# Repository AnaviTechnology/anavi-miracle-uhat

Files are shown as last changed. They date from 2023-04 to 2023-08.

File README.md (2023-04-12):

# ANAVI Miracle uHAT

ANAVI Miracle uHAT is an open source hardware Raspberry Pi add-on board for controlling NeoPixel RGB LED strip powered by free and open source software. It features:

* Slot for addressable NeoPixel RGB LED strip like WS2812B, WS2812B, WS2811, etc.
* Power input barrel jack for the addressable RGB LED strip
* Slot for PIR motion sensor
* Slot for I2C mini OLED display
* Slots for up to 3 plug and play I2C sensors for temperature, barometric pressure, humidity and light
* UART (Universal asynchronous receiver/transmitter) pins for debugging
* EEPROM

# License

The project is released under the [Creative Commons Attribution-ShareAlike 4.0 International (CC BY-SA 4.0)](https://creativecommons.org/licenses/by-sa/4.0/).

Note: This is a human-readable summary of (and not a substitute for) the [license](https://creativecommons.org/licenses/by-sa/4.0/legalcode).

You are free to:

Share — copy and redistribute the material in any medium or format Adapt — remix, transform, and build upon the material for any purpose, even commercially. The licensor cannot revoke these freedoms as long as you follow the license terms. Under the following terms:

Attribution — You must give appropriate credit, provide a link to the license, and indicate if changes were made. You may do so in any reasonable manner, but not in any way that suggests the licensor endorses you or your use. ShareAlike — If you remix, transform, or build upon the material, you must distribute your contributions under the same license as the original. No additional restrictions — You may not apply legal terms or technological measures that legally restrict others from doing anything the license permits. Notices:

You do not have to comply with the license for elements of the material in the public domain or where your use is permitted by an applicable exception or limitation. No warranties are given. The license may not give you all of the permissions necessary for your intended use. For example, other rights such as publicity, privacy, or moral rights may limit how you use the material.

You will have to provide a link to the original creator of the project https://www.anavi.technology on any documentation or website.

Credit can be attributed through a link to the creator website: https://www.anavi.technology

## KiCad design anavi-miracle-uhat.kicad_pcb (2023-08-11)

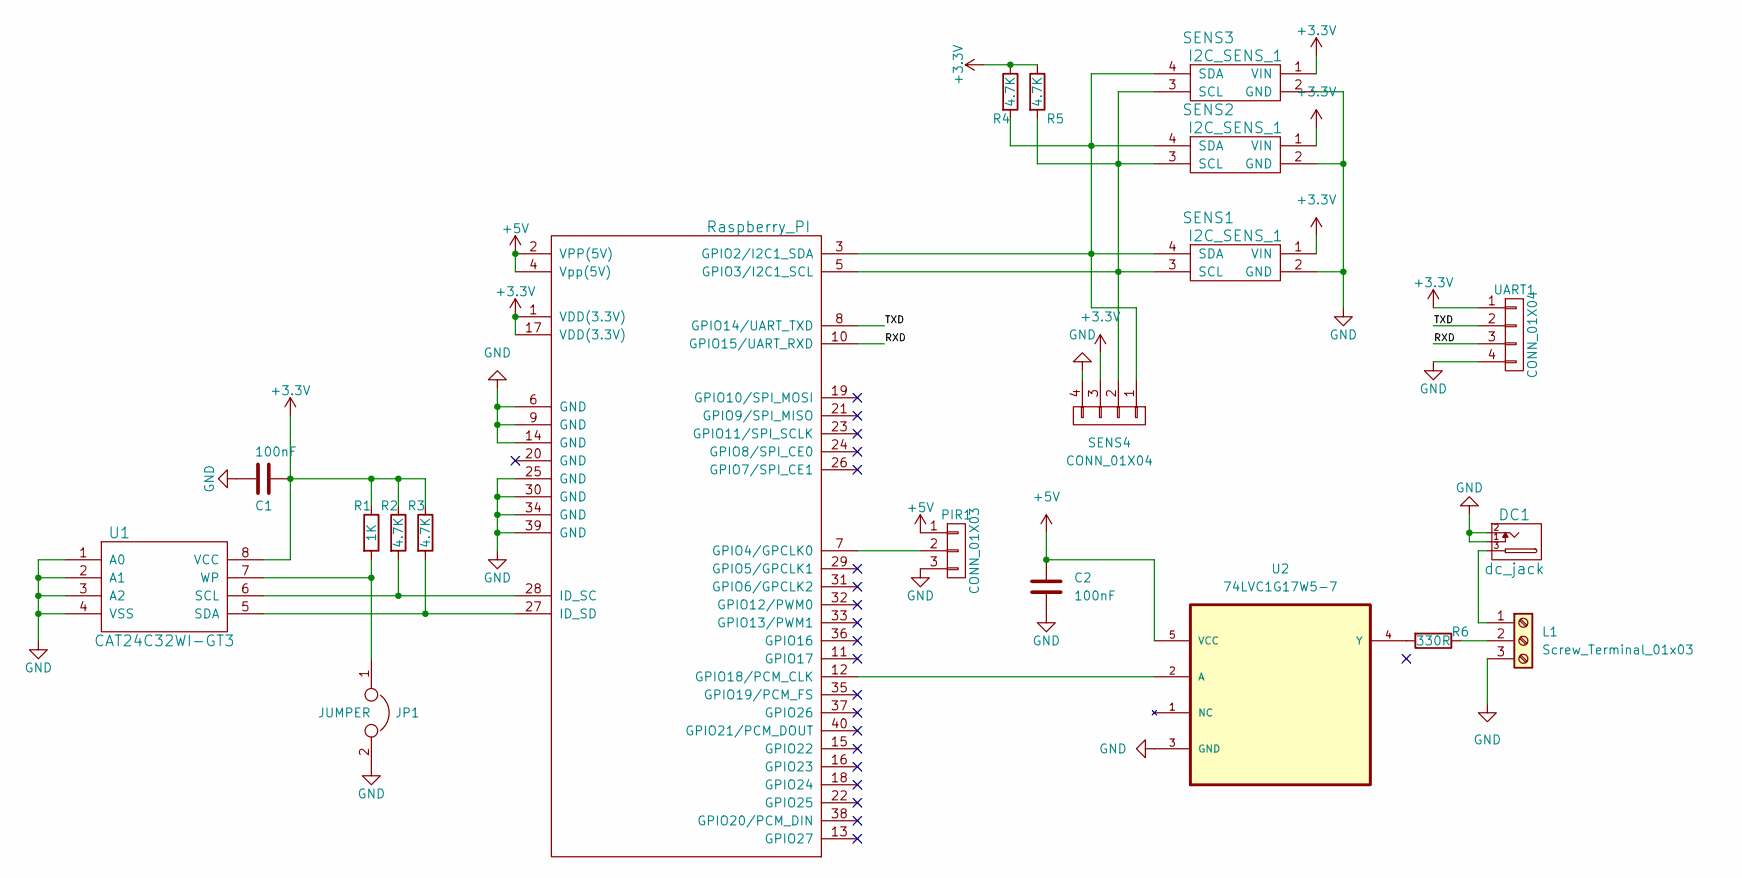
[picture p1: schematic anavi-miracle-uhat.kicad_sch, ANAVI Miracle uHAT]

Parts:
C1, C2: 100nF; C_0603_1608Metric_Pad1.08x0.95mm_HandSolder
DC1: dc_jack; dc_socket
JP1: JUMPER; PinHeader_1x02_P2.54mm_Vertical
L1: Screw_Terminal_01x03; TerminalBlock_Phoenix_MKDS-1,5-3_1x03_P5.00mm_Horizontal
PIR1: CONN_01X03; PinHeader_1x03_P2.54mm_Vertical
R1: 1K; R_0603_HandSoldering
R2, R3, R4, R5: 4.7K; R_0603_HandSoldering
R6: 330R; R_0603_1608Metric_Pad0.98x0.95mm_HandSolder
RASP_CONN1: Raspberry_PI; PinHeader_2x20_P2.54mm_Vertical
SENS1, SENS2, SENS3: I2C_SENS_1; PinHeader_1x04_P2.54mm_Vertical
SENS4: CONN_01X04; PinHeader_1x04_P2.54mm_Vertical
U1: CAT24C32WI-GT3; DIP-8_W7.62mm
U2: 74LVC1G17W5-7; SOT95P280X145-5N; MPN 74LVC1G17W5-7
UART1: CONN_01X04; PinHeader_1x04_P2.54mm_Vertical

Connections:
+3V3: C1.1, R1.1, R2.1, R3.1, R4.1, R5.1, RASP_CONN1.1 (VDD(3.3V)), RASP_CONN1.17 (VDD(3.3V)), SENS1.1 (VIN), SENS2.1 (VIN), SENS3.1 (VIN), SENS4.3, U1.8 (VCC), UART1.1; also elsewhere on the board
+5V: C2.1, PIR1.1, RASP_CONN1.2 (VPP(5V)), RASP_CONN1.4 (Vpp(5V)), U2.5 (VCC); also elsewhere on the board
/RXD: RASP_CONN1.10 (GPIO15/UART_RXD), UART1.3; also elsewhere on the board
/TXD: RASP_CONN1.8 (GPIO14/UART_TXD), UART1.2; also elsewhere on the board
GND: C1.2, C2.2, DC1.1, DC1.2, JP1.2, L1.3, PIR1.3, RASP_CONN1.6 (GND), RASP_CONN1.9 (GND), RASP_CONN1.14 (GND), RASP_CONN1.25 (GND), RASP_CONN1.30 (GND), RASP_CONN1.34 (GND), RASP_CONN1.39 (GND), SENS1.2 (GND), SENS2.2 (GND), SENS3.2 (GND), SENS4.4, U1.1 (A0), U1.2 (A1), U1.3 (A2), U1.4 (VSS), U2.3 (GND), UART1.4; also elsewhere on the board
unnamed: DC1.3, L1.1
unnamed: JP1.1, R1.2, U1.7 (WP)
unnamed: L1.2, R6.1
unnamed 8: PIR1.2, RASP_CONN1.7 (GPIO4/GPCLK0); also elsewhere on the board
unnamed: R2.2, RASP_CONN1.28 (ID_SC), U1.6 (SCL)
unnamed: R3.2, RASP_CONN1.27 (ID_SD), U1.5 (SDA)
unnamed: R4.2, RASP_CONN1.3 (GPIO2/I2C1_SDA), SENS1.4 (SDA), SENS2.4 (SDA), SENS3.4 (SDA), SENS4.1
unnamed: R5.2, RASP_CONN1.5 (GPIO3/I2C1_SCL), SENS1.3 (SCL), SENS2.3 (SCL), SENS3.3 (SCL), SENS4.2
unnamed: R6.2, U2.4 (Y)
unnamed: RASP_CONN1.12 (GPIO18/PCM_CLK), U2.2 (A)

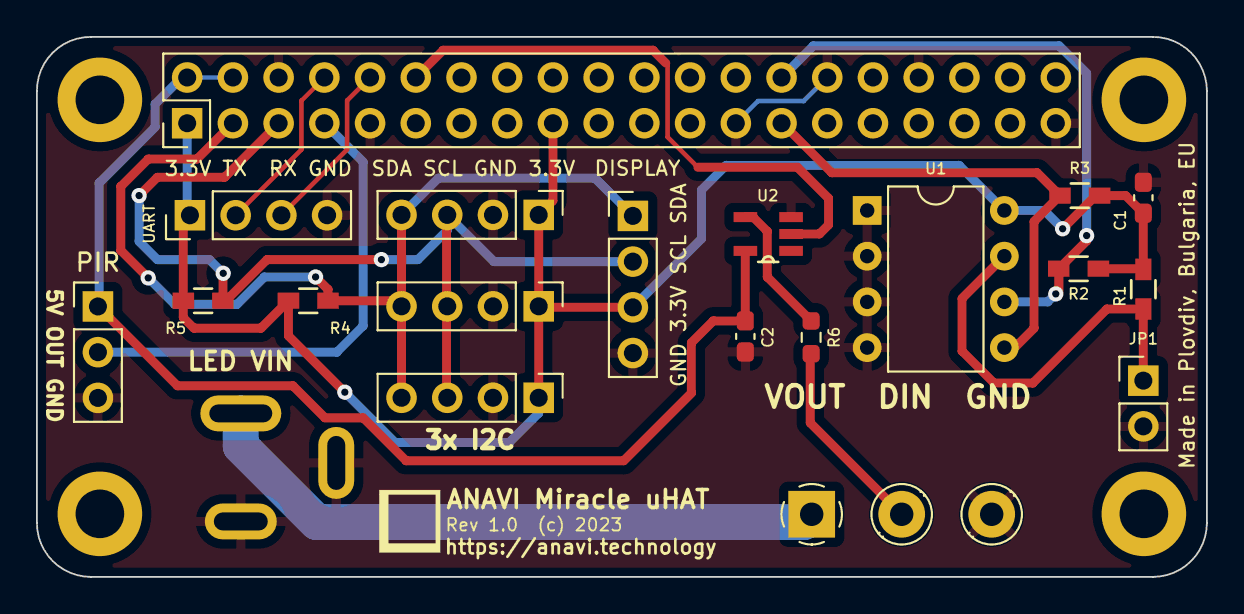
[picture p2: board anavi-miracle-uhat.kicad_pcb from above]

Board: 2 copper layers, 65.0 x 30.0 mm, 24 parts (0 on the bottom side), 15 nets.

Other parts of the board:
PIR: CONN_01X03; PinHeader_1x03_P2.54mm_Vertical
REF1, REF2, REF3, REF4: MountingHole_2.7mm_M2.5_DIN965_Pad
UART: CONN_01X04; PinHeader_1x04_P2.54mm_Vertical

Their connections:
+3V3: UART.1; also elsewhere on the board
+5V: PIR.1; also elsewhere on the board
/RXD: UART.3; also elsewhere on the board
/TXD: UART.2; also elsewhere on the board
GND: PIR.3, UART.4; also elsewhere on the board
unnamed 8: PIR.2; also elsewhere on the board

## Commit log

2023-04-12 ANAVI Miracle uHAT: Initial commit
    Raspberry Pi add-on board for an addressable LED strip.
    [anavi-light-2023-04-12-22-15-59.sch, anavi-miracle-uhat.kicad_pcb, anavi-miracle-uhat.kicad_sch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]
2023-04-14 .gitignore: Ignore backups
    Ignore KiCad backup files.
2023-04-14 anavi-miracle-uhat: Adjust LED strip connector
    Adjust the addressable LED strip connector.
    [anavi-miracle-uhat.kicad_pcb, anavi-miracle-uhat.kicad_sch]
2023-05-07 anavi-miracle-uhat.kicad_pcb: Labels
    Adjust labels on front silkscreen.
    [anavi-miracle-uhat.kicad_pcb]
2023-08-11 anavi-miracle-uhat: Add assembly notes
    Add assembly notes to the front fabrication layer.
    [anavi-miracle-uhat.kicad_pcb]

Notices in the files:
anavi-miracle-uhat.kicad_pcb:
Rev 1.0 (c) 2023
